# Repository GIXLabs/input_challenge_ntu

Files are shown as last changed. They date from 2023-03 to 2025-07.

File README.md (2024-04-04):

# Challenge
You are tasked with creating a hardware device to play [Tetris in the browser](https://tetris.com/play-tetris). We have provided some pre-programmed boards that handle most of the electronics and coding, but you will need to build the physical interface.

You must choose a target user and scenario for whom you're making your device.

# Table of Contents
- [Procedure](#procedure)
- [Materials](#materials)
- [Electrical Assembly](#electrical-assembly)
- [Code](src/)
- [Mechanical Design](cad/)
- [Extra Credit](#extra-credit)

# Procedure
1. [Assemble the electronics](#electrical-assembly) and see how they work with Tetris. Try playing it on a computer and make sure you get the button presses you expect, but don't feel the need to edit the code at this point. See the table in the [Operation section](#operation) for what the buttons are supposed to do.
    1. You may find that your computer behaves funny when you plug the device in. The device is trying to press the down arrow regularly, but you can turn that off by either turning the potentiometer all the way down or by disconnecting the potentiometer.
1. Come up with a target user and scenario for whom you're making your device. Spend about 10 minutes coming up with this.
1. Build the enclosure using the tools in the Prototyping Lab. Cardboard and hot glue is perfectly fine, but feel free to stretch a little and try [using the lasers](cad/README.md) or any other tool in the main area. Making a basic lasercut enclosure only takes about 20 minutes, even with no experience.
1. Test your prototype, in other words, [play Tetris](https://tetris.com/play-tetris).
1. Make your prototype better based on your test. Consider trying out one of the challenges in the [Extra Credit](#extra-credit) section.

# Materials
Supplies laid out
- Raspberry Pi Pico main board (yours will have less green blocks)
- Micro USB cable (not pictured)
- Switches
- Potentiometer
- Anything you can find in the Prototyping Lab

# Electrical Assembly
The button wires go into the green terminal blocks with two holes. It does not matter which end goes into which hole since these buttons are not polarized. You will need to depress the square on the top of the green terminal block to let the wire slip in.

Gif of plugging wires in

The potentiometer wires go into the green terminal blocks with three holes. The black wire needs to go into the center hole, but the other two can be placed in either side hole (but not the same one!).

Wired potentiometer

# Operation

| Pin | Keystroke |
| --- | --- |
| GP2 | Left Button |
| GP3 | Right Button |
| GP4 | Up Button (rotate the piece) |
| GP5 | Spacebar (drop the piece)* |

*The code loaded on the device does not implement the spacebar button. For information on editing the code, [click here](src/). To achieve high scores, you'll need that functionality.

The potentiometer (knob) controls how fast bricks fall by "feathering" the down button. If the potentiometer is not wired, this feature will be deactivated.

# Extra Credit
- Fabrication
    - Lasercut and heat bend a controller.
    - 3D print your controller. (very hard, but doable with the faster printers)
- Electronics
    - Find a different button to use with the board in the Prototyping Lab.
    - Use something other than a real button as a button.
- Coding
    - Implement the spacebar code.
    - Implement a series of commands instead of just one button press. For example, pressing the button connected to GP4 could send several rotation commands instead of one.
    - Edit the potentiometer code to have the blocks fall faster or slower.

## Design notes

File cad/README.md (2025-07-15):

# Making a basic laser enclosure (no design experience needed)
1. [Open up a box generator.](https://en.makercase.com/#/basicbox)
    1. We recommend using a thickness of 0.125 inches.
    1. Adding fingers will make assembly easier. Change the "Edge Joints" to fingers. Finger size doesn't matter much, but the more fingers you have, the harder it will be to fit together.
    1. Change the size of the box. The default box is huge, so you may need to change the dimensions to fit the printed circuit board (PCB).
    1. Download files as svg. No need to change any of the other settings.
1. Ask a member of staff to invite you to the Glowforge system. You will need to sign up for an account, but it is free. Please skip any features that ask for a credit card.
    1. You will get an email and you'll need to click "Click here to get started." Feel free to skip the tutorials.
1. "Create a new design" and "Upload a file" in the [Glowforge interface](https://app.glowforge.com)

    Image of Glowforge home screen

1. Find a material of your choice (probably cardboard) in the laser material storage and put a sheet of it in your laser on the black honeycomb tray. Position doesn't matter much, and you can close the lid once you have the piece in. If you can, try to use pieces that already have something cut out of them. The numbers in the top right of the Glowforge interface indicate which laser is yours. The number on the machine is near the barcode.
1. You will need to set the material to Glowforge preset on the shelves in the top left of the Glowforge interface. You may have to search using the search box.

    Image showing where to select materials
    
    1. Greyed out parts are ones outside the Glowforge's cuttable area and will need to be moved onto the material.

1. Add [button holes (copy and paste to get multiple)](button_hole.svg), [potentiometer hole](potentiometer_hole.svg), and [micro-USB hole](usb_hole.svg). There is a download symbol on each of these pages that you'll need to use. You may also want this [rectangle](rect.svg) and [circle](circle.svg) file, which you can stretch and resize in the Glowforge interface.

    Image of Glowforge interface

1. In the Glowforge interface, click and drag those holes around on the generated box pieces to place them where you want them. Be careful not to accidentally scale the pieces.

1. Set the text to "Ignore."

    Image showing where Ignore is found

1. Make sure that all of your parts are on the material in the laser and are not greyed out. You can box select groups of them and move them around.
    1. If you are using scraps, you can move items you don't want to cut outside the cuttable area. Anything greyed out won't be cut, which is sometimes desirable.
1. Click "Print" in the top right of the interface.

    Image showing the Print button

1. Press the big glowing button on the Glowforge and stay to watch your cut. Watching your cut is important as fires are common in lasers.
1. Once the laser has stopped making noise, you can open the lid and pull the parts out (don't worry, they aren't hot).
1. You've made your first box! Test it out and iterate!

# Dimensions
The main board outline is 2.2 inches wide by 2.1 inches deep x 1.6 mm tall. Please pardon the mixed units, but that's just how PCB design is.

# Models
The 3D model for the carrier board (in both Fusion 360 format and STL) are located above. If you are not proficient in Fusion 360, the STL file can be used with TinkerCAD to add features. It will be tough to 3D print something in time, but it could be ready by the time you get back for the happy hour.

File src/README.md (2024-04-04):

# Editing Code
The Raspberry Pi Pico is programmed using CircuitPython, which requires a different method of uploading code than you may be used to with Arduinos.

1. Plug in your Pico main board and open the drive on your computer marked `CIRCUITPY`.
1. Right click or two finger click, select "Open With," and choose either TextEdit (Mac) or NotePad (PC).
1. Change the code however you would like, whether that's copying and pasting from the code we have provided or by coming up with your own novel code.
1. Save. Saving will automatically load the code on the Pico and start running. To sound fancy, refer to this as "flashing the code." 

# Mu Code Editor
Although you can edit the code using TextEdit or Notepad, those are not the preferred tools. They do not have code complete, color-coded text, or many debugging tools.

We recommend using [Mu Editor](https://codewith.mu/en/download) as it has a built in serial terminal that will allow you to debug the code with print statements.

# Keycodes
If you would like to change which keystrokes the board makes, you will need this [list of keycodes](https://docs.circuitpython.org/projects/hid/en/latest/).

# Required Libraries
Your board should have all of the following already, but you will need to add them if you reformat your device.

### Built-In
- time
- board
- analogio

### Put in lib folder (download bundle from [here](https://circuitpython.org/libraries))
- adafruit_hid
- adafruit_debouncer
- adafruit_ticks

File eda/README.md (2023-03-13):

# Schematic

![Schematic]()

# Buttons
Each button is wired between a digital pin on the Pico and ground, making it active Low and working well with the internal pull-up resistors. This means that when the button is pressed, the pin reads 0V (also known as Ground, Low, and False). When the button is released, the internal pull-up resistors pull the pin to 3.3V (also known as VCC, High, and True). The pull-up resistors ensure that the pin is pulled to a known state when not pressed.

The wires are the same color because switches can be wired up in either direction and still work. In other words, they are not polarized components. Just make sure that two wires coming from the buttons go to different ports on the same terminal block.

![Image of wired terminal blocks]()

# Knobs
Each potentiometer has 3 wires: power, signal, and ground. The signal pin is tied to one of the analog pins on the Pico. 

A potentiometer is basically one long resistor with a third connection somewhere in the middle of the resistor. By turning the knob, you change where that third connection is made, changing the resistance on either side of the third connection. Note: the overall resistance does not change, just how that resistance is distributed. This change in the position of the third connection results in a change in voltage, which the Pico can read on an analog pin.

That change in voltage is converted to something in the code.

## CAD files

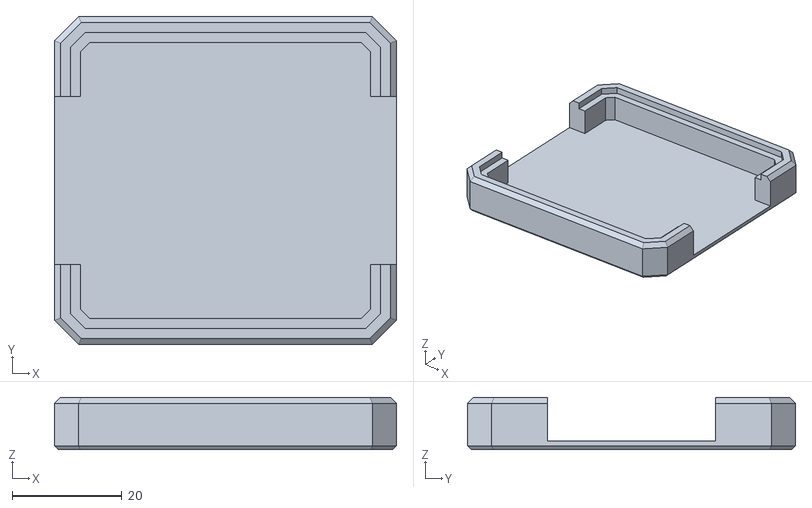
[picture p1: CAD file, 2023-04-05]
cad/carrier.stl
62.2 x 59.7 x 9.54

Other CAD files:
cad/carrier.f3d

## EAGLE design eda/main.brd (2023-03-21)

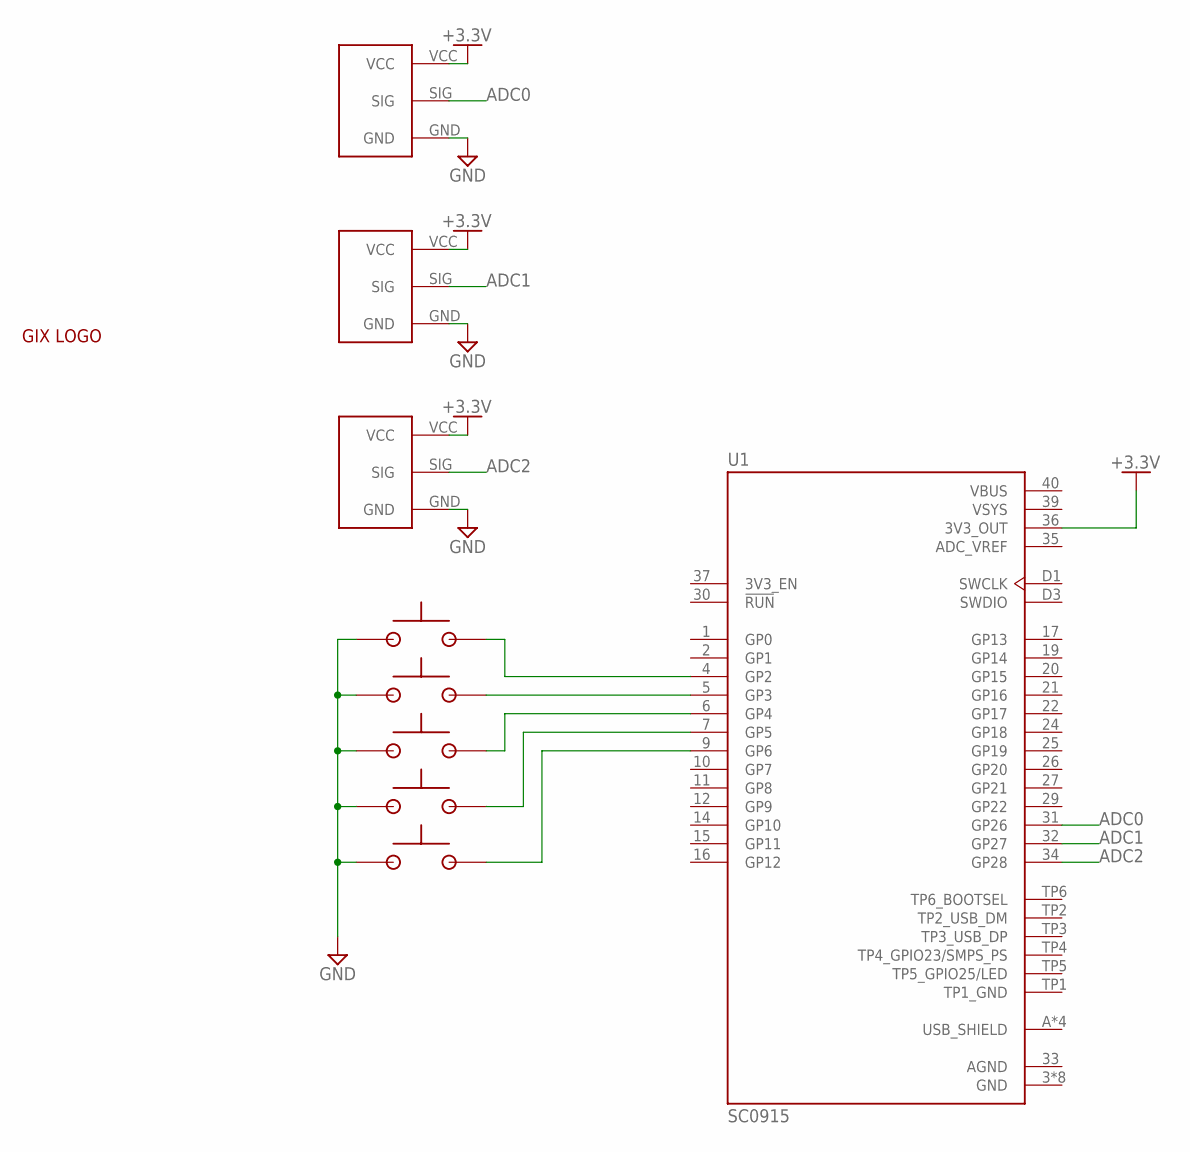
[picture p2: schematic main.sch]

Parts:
U1: SC0915; MODULE_SC0915
U$1, U$2, U$3, U$4, U$5: TERMINAL_BLOCK
U$6, U$7, U$8: 3PIN_SENSOR; TERMINAL_BLOCK_3P
U$9: LOGO

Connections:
+3.3V: U1.36 (3V3_OUT), U$6.VCC, U$7.VCC, U$8.VCC
ADC0: U1.31 (GP26), U$6.SIG
ADC1: U1.32 (GP27), U$7.SIG
ADC2: U1.34 (GP28), U$8.SIG
ADC_VREF: U1.35 (ADC_VREF)
AGND: U1.33 (AGND)
GND: U1.3 (GND), U1.8 (GND), U1.13 (GND), U1.18 (GND), U1.23 (GND), U1.28 (GND), U1.38 (GND), U1.D2 (GND), U$1.P$1, U$2.P$1, U$3.P$1, U$4.P$1, U$5.P$1, U$6.GND, U$7.GND, U$8.GND
unnamed: U1.6 (GP4), U$3.P$2
unnamed: U1.5 (GP3), U$2.P$2
unnamed: U1.4 (GP2), U$1.P$2
unnamed: U1.7 (GP5), U$4.P$2
unnamed: U1.9 (GP6), U$5.P$2
TP1_GND: U1.TP1 (TP1_GND)
USB_SHIELD: U1.A (USB_SHIELD), U1.B (USB_SHIELD), U1.C (USB_SHIELD), U1.D (USB_SHIELD)
VBUS: U1.40 (VBUS)
VSYS: U1.39 (VSYS)

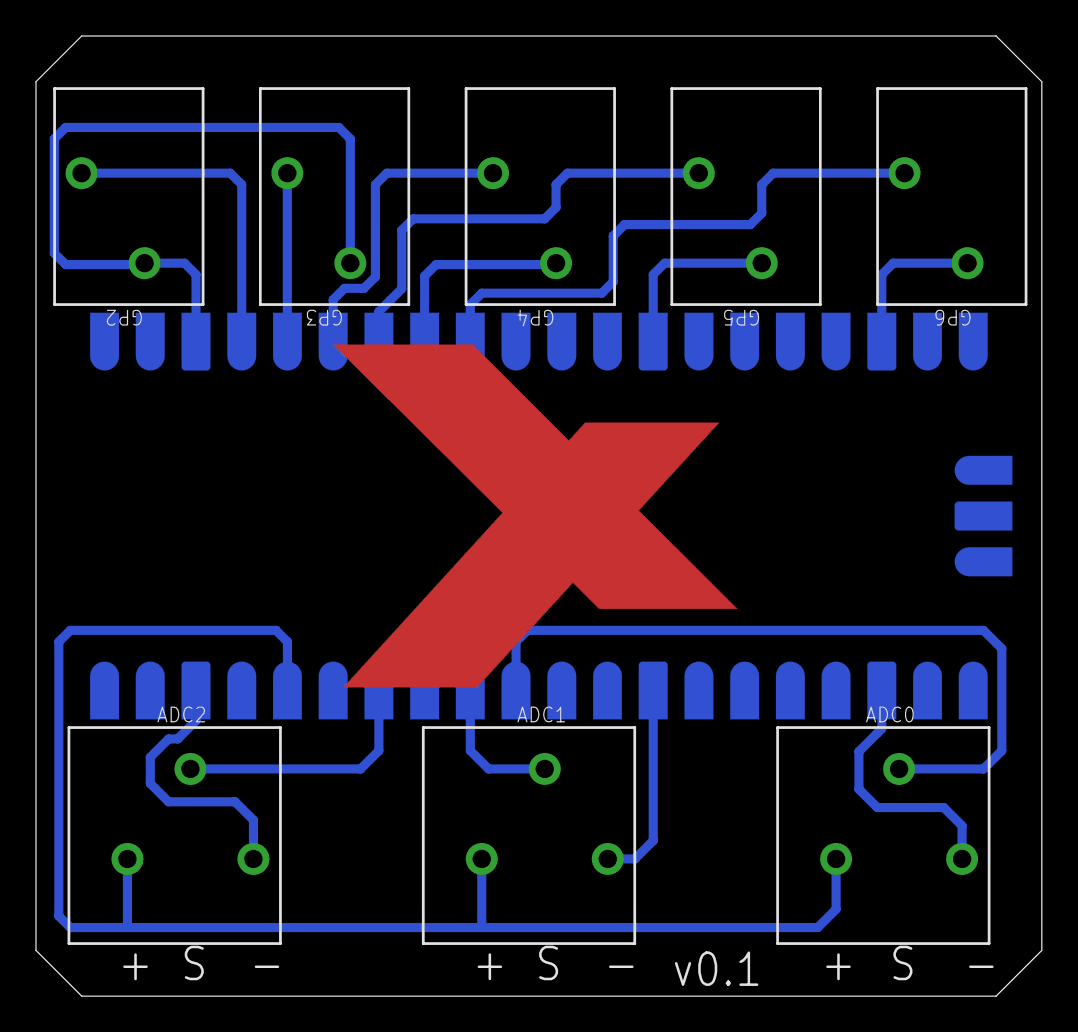
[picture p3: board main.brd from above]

Board: 2 copper layers, 55.9 x 53.3 mm, 10 parts (1 on the bottom side), 11 nets.

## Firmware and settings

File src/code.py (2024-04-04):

# Import modules from standard library
import board

# Import Adafruit-specific libraries
from adafruit_hid.keycode import Keycode

from input_code import Controller

ANALOG_INPUT_PIN = board.A0

button_assignments = {
    board.GP2: Keycode.LEFT_ARROW,
    board.GP3: Keycode.RIGHT_ARROW,
    board.GP4: Keycode.UP_ARROW
}

# Set up Pico pin ADC0 as an analog input
pico = Controller(ANALOG_INPUT_PIN)

# Setup the Potentiometer
pico.setup_potentiometer()

pico.setup_buttons(button_assignments)

while True:
    pico.handle_button_presses()

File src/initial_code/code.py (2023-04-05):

# Import modules from standard library
import board
import usb_hid
from digitalio import DigitalInOut, Pull
import time
from analogio import AnalogIn

# Import Adafruit-specific libraries
from adafruit_debouncer import Debouncer
from adafruit_hid.keyboard import Keyboard
from adafruit_hid.keycode import Keycode

# Returns a dictionary that pairs the debounced button object with a keystroke, allowing for slightly more readable code later
def setup_button(pin, keystroke):
    dio = DigitalInOut(pin)
    # Sets the input pin as a pull up, so the pin will read High when not actuated and Low when actuated
    dio.pull = Pull.UP
    button = {
            'KEYSTROKE': keystroke, 
            'OBJECT': Debouncer(dio)
            }
    return button

# Set up Pico pin ADC0 as an analog input
analog_in = AnalogIn(board.A0)

# The following takes two readings from the analog pin and compares them. If they are close to the same value, it assumes a potentiometer is connected.
test_val_one = analog_in.value
time.sleep(.1)
test_val_two = analog_in.value
potentiometer_present = False
if abs(test_val_one - test_val_two) < 20:
    print("Potentiometer detected")
    potentiometer_present = True
else:
    print("No potentiometer detected")

# Create a keyboard object that handles the USB protocol for sending keystrokes
keyboard = Keyboard(usb_hid.devices)

last_down = time.monotonic() # Set the most recent sending of the down key to the time of bootup
spacing = 0 # This is the time between down presses (speed)

# The following sets up all the pins and keyboard outputs associated with those pins
buttons = []
# The next 3 lines are the ones you will most likely want to edit
buttons.append(setup_button(board.GP2, Keycode.LEFT_ARROW))
buttons.append(setup_button(board.GP3, Keycode.RIGHT_ARROW))
buttons.append(setup_button(board.GP4, Keycode.UP_ARROW))

while True:
    # Iterates through the list of buttons
    for button in buttons:
        button['OBJECT'].update()
        if button['OBJECT'].fell:
            print("Button pressed")
            keyboard.send(button['KEYSTROKE'])

    # Read the value from the potentiometer
    pin_val = analog_in.value

    if pin_val > 500 and potentiometer_present: # Only true if the potentiometer has been turned a little and a potentiometer was detected on boot
        # Scale the value from the pin linearly to change the spacing between down clicks (speed)
        spacing = 65085 / (4 * pin_val - 1800)

        # Compare the current time to the time the last down command was sent
        # If enough time has elapsed send a rotation command and set the most recent rotation time to now
        if time.monotonic() - last_down > spacing:
            keyboard.send(Keycode.DOWN_ARROW)
            last_down = time.monotonic() 

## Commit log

2023-03-13 Initial commit. Needs code. 3 terminal block needs updating and board needs rerouting.
    [main.brd, main.sch]
2023-03-21 Modified board to reflect fixed 3 pos footprint.
    [main.brd, main.sch]
2023-03-24 Added text for electrical assembly and placeholders for the images.
2023-03-28 Added single button example code.
2023-03-28 Added potentiometer wiring image.
2023-03-29 Added mapping table from buttons to keystrokes. Cleaned up the prompt. Removed schematics from table of contents.
2023-03-30 Added basic main code file. Still needs other buttons implemented.
2023-03-30 Updated main code. Changed the button list to a list of dictionaries to reduce spaghetti.
2023-03-30 Fixed fatal syntax error in dictionary assignment.
    [code.py]
2023-04-04 Added code with intentional lack of functionality to be initially flashed to the boards.
2023-04-05 Added CAD models for the carrier.
    [carrier.f3d, carrier.stl]
2023-04-05 Added link to CAD models in main README.md
2023-04-05 Added more information on programming the boards.
2023-04-05 Added links to lasercutting tutorial.
2023-04-06 Added coment about the amount of terminal blocks on the main board.
2024-03-29 Added svgs for different holes.
2024-04-01 Added lots of details about the lasering process. To Do: Add images of Glowforge interface.
2024-04-01 Added links to lasercutting tutorial from main page.
2024-04-02 Added more detail about greyed out parts, finding material, and changed order of items.
2024-04-02 Added clarification to material placement, finger size, and Glowforge number.
2024-04-04 Fixed some bugs with potentiometer by adding more checks.
    [code.py, input_code.py]
2024-04-04 Fixed type in potentiometer wiring section.
2025-07-15 Changed cherry plywood to general laser material.
